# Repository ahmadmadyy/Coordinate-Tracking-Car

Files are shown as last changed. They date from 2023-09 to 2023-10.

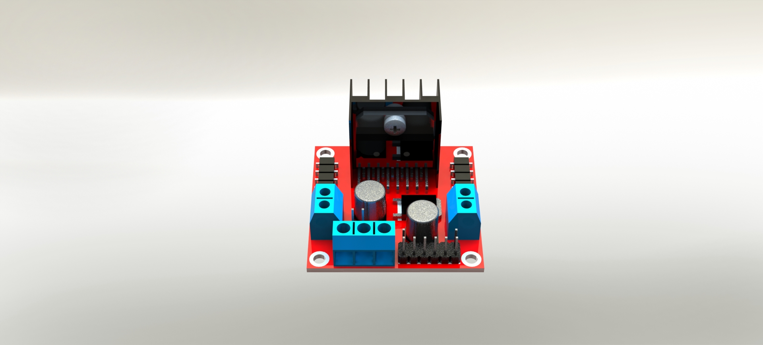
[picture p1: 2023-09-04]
Hardware Design/h_bridg-motor-drive-l298n-1.snapshot.1/Assem final (H_Bridg)/Assem final (H_Bridg)/Untitled63.JPG

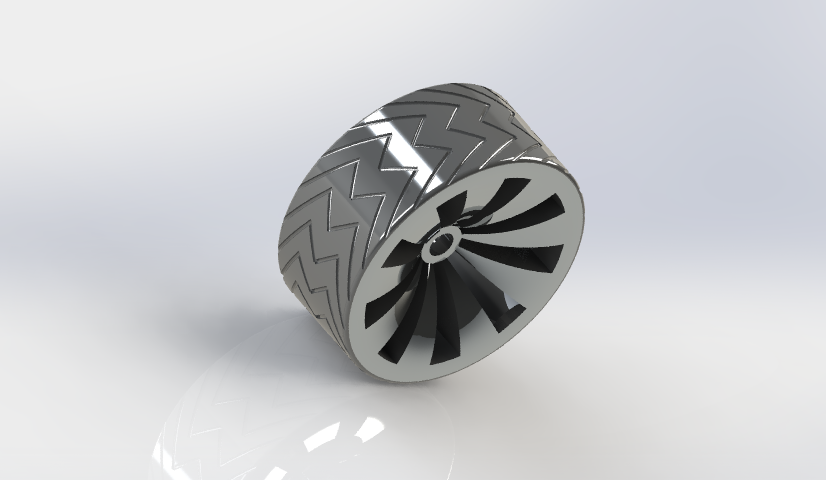
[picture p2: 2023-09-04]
Hardware Design/Capture 2.png

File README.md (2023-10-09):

# Coordinate-Tracking-Car
An AVR-controlled Arduino car that takes as input x and y coordinates from a keypad and uses an encoder sensor with PID Control and PWM to reach its destination.

## Software Design
The software design folder contains the 2 files, an Arduino file that has 2 codes the normal project code and another implemented with FreeRTOS. The second file contains the SIMULINK simulation file and PID controller design.

## Hardware Design 
This folder includes all the Solidworks files and libraries used to design the hardware used.

### Other folders include the images and videos of the project, circuit design and simulation, and the PDF report of the project.

## Youtube Video: 
Video (https://www.youtube.com/watch?v=sBs9JzHG70Q)

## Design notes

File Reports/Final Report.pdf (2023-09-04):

Project Final Report | Mechatronics Engineering MCTR601
Spring 2021

1

# German University in Cairo

## Mechatronics Engineering (MCTR601)

## Coordinate Tracking Car Team 7

Name | ID | Lab Number
Ahmed Khaled Mady | 46-798 | 55
Amro Hassan Abdellatif | 46-3027 | 53
Mostafa Ahmed Kashaf | 46-5456 | 53

Project Final Report | Mechatronics Engineering MCTR601
Spring 2021

2

### Table of Contents

Project Final Report | Mechatronics Engineering MCTR601
Spring 2021

3

## 1. Project Description

The micro-controlled car will be awaiting an input in the form of x-y coordinates through a keypad(3x4). The objective of the car is to reach the desired location. For the car to reach the location, an encoder that measures the number of revolutions required by the motor to reach its destination is used. The output of the encoder will be received by the microcontroller as x-y coordinates to maintain closed-loop feedback control. These x-y coordinates will be calculated using a certain algorithm to be able to know the required speed (v) and rotational torque (θ) of the car. Then the speed and rotational torque will be translated into angular velocity for each wheel (ω_L,ω_R) to accurately reach the destination. When the car reaches its destination, the car will stop.
The car uses a DC gear motor as an actuator and an Infrared motor speed sensor that will be fed back to Arduino’s ATmega328p MCU to maintain a closed loop.
The car will move forward using 2 wheels that are controlled by the motor driver that is controlled by the Arduino development board PWM modes. During turns, left or right, the steering technique is made by increasing the speed of a wheel while keeping the other constant. The turn is made by the single caster wheel.
The car changes its’s angle by measuring the arctan of the y coordinate/ x coordinate and multiplying it with the pulses needed by the motor to rotate. The car is assumed to always given positive x and y coordinates (1ST Quadrant) so the right wheel is always given no PWM signal unlike the left wheel which will cause the rotation.
The x-y coordinates are then used to calculate the needed moving distance, or hypotenuse.

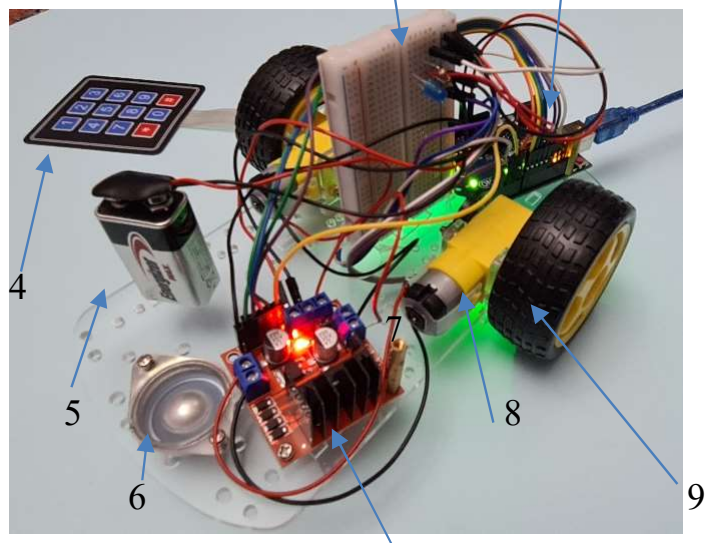
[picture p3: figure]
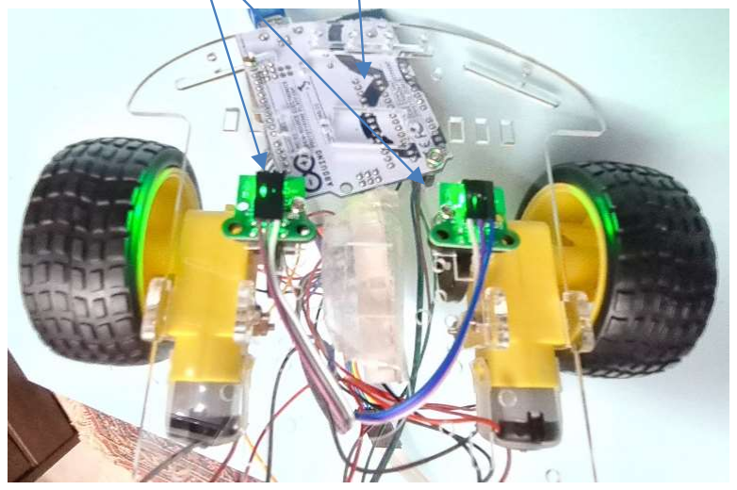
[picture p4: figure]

Project Final Report | Mechatronics Engineering MCTR601
Spring 2021

4

Part number | Name
1 Breadboard
2 Arduino UNO
3 LM393 IR Speed Sensor
4 Keypad
5 9V Battery
6 Caster Wheel
7 L298N Motor Driver
8 DC Gear Motor
9 Wheels

2
1
3 2

7

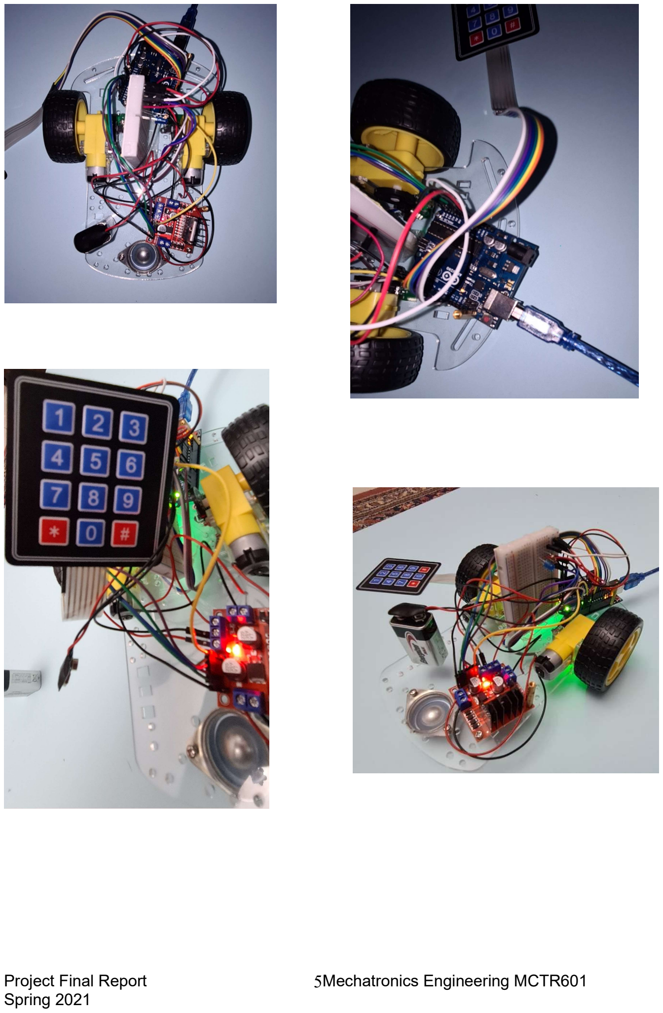
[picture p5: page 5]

Project Final Report | Mechatronics Engineering MCTR601
Spring 2021

5

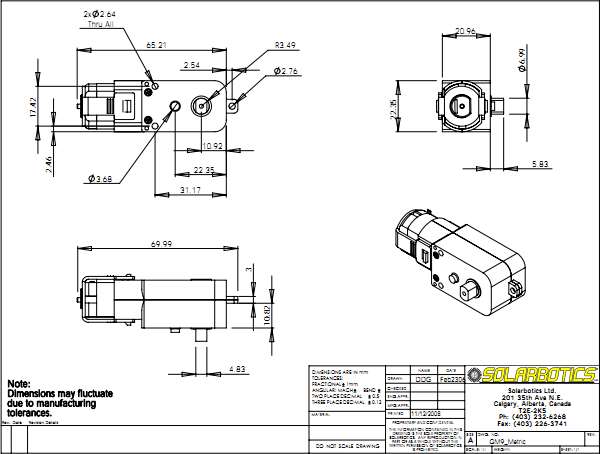
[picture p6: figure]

Project Final Report | Mechatronics Engineering MCTR601
Spring 2021

6

## 2. Methodology

## 2.1 Mechanical design

DC Gear Motor:
Specifications:
Description: 90-degree
Gear ratio: 143:1

### 3 V Operation:

No-load RPM: ~ 40
No-load current: ~ 50 mA
Stall current: ~ 400 mA
Stall torque: ~ 44 oz-in

### 6 V Operation:

No-load RPM: ~ 78
No-load current: ~ 52 mA
Stall current: ~ 700 mA
Stall torque: ~ 76 oz-in
Weight: 33 g

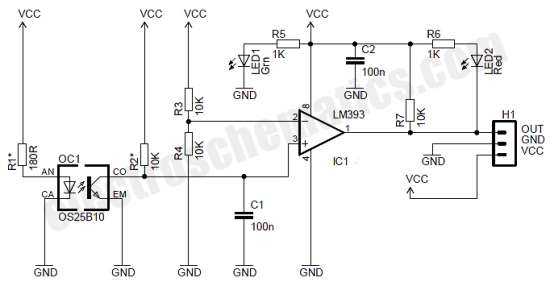
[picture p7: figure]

Project Final Report | Mechatronics Engineering MCTR601
Spring 2021

7

LM393 IR Speed Sensor

Note that one side of the optical sensor holds s a light emitting diode, and a photo transistor on the other side. If the visual path is not blocked, phototransistor would conduct, but when something blocked the light falling on the photo transistor it wouldn’t conduct. So, an encoder disc (with a proper encoder resolution) can be placed in the slot of the optical sensor to count rotation rate of a connected wheel/motor. The encoder disc (also known as index wheel) in the above image have multiple slots/holes.

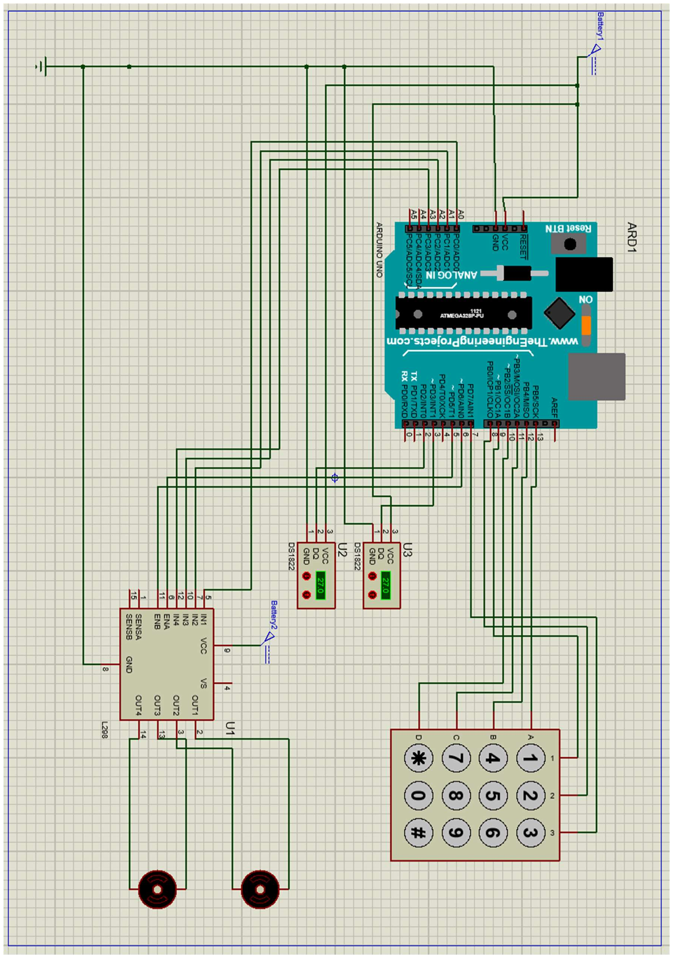
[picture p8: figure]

Project Final Report | Mechatronics Engineering MCTR601
Spring 2021

8

## 2.2 Electrical design

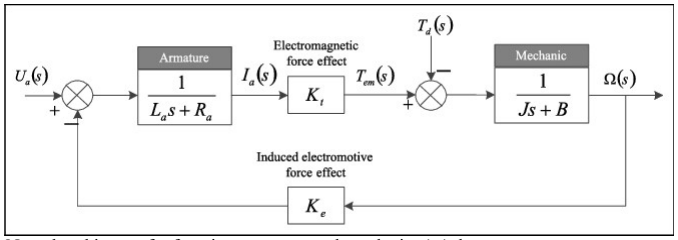
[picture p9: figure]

Project Final Report | Mechatronics Engineering MCTR601
Spring 2021

9

## 2.3 Control

### 1.3.1. Modeling

a. DC MOTOR:
From the datasheet of the DC geared motor, the following parameters were obtained:
(J) Moment of inertia of the rotor 0.1 kg.m
(B) Motor viscous friction constant 0.3550510258 N.m.s
(Ke) Electromotive force constant | 0.25 V/rad/sec
(Kt) Motor torque constant | 0.01 N.m/Amp
(R) Electric resistance | 0.4222474487 Ohm
(L) Electric inductance | 0.05 H
Transfer Function:

### 1.3.2. Analysis

Note that this transfer function outputs angular velocity (ω), but our purposes are revolutions, so an integrator was added at the output.
On MATLAB, the transfer function was generated
L_a = 0.05;
J_m = 0.1;
B = 0.3550510258;
R_a = 0.4224744871;
K_e = 0.25;
K_t = 0.01;
Armature= tf([1],[L_a R_a]); A = series(K_t,Armature);
Mechanical = tf([1],[J_m B]); M = series(A,Mechanical);
W = feedback(M,K_e);
G = series(W,tf([1],[1 0])

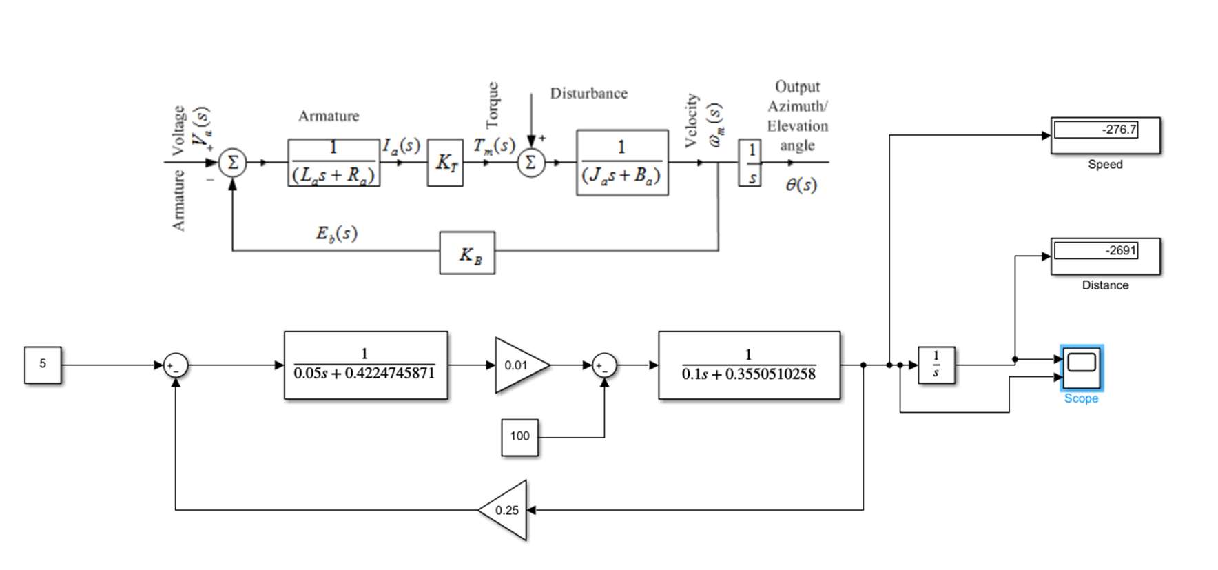
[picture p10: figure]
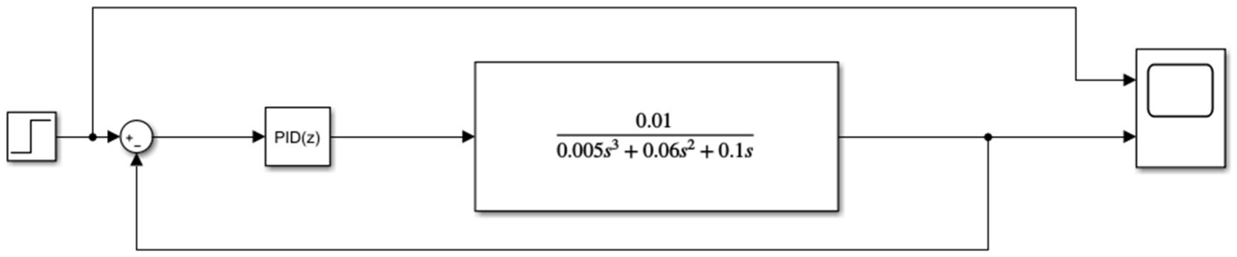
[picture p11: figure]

Project Final Report | Mechatronics Engineering MCTR601
Spring 2021 | 10

SIMULINK DIAGRAM:

Plant:
G =

0.01
-------------------------------0.005 s^3 + 0.06 s^2 + 0.1525 s

Continuous-time transfer function.

### 1.3.3. Controller Design

To design our controller, we modeled our system on SIMULINK:

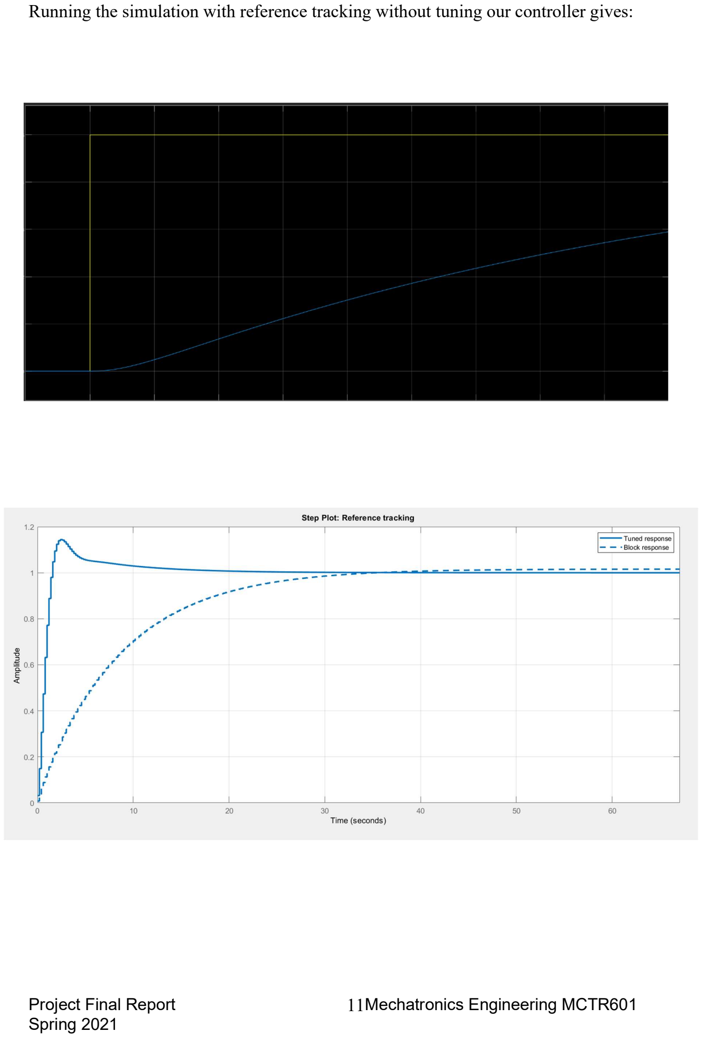
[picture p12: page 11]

Project Final Report | Mechatronics Engineering MCTR601
Spring 2021 | 11

Running the simulation with reference tracking without tuning our controller gives:

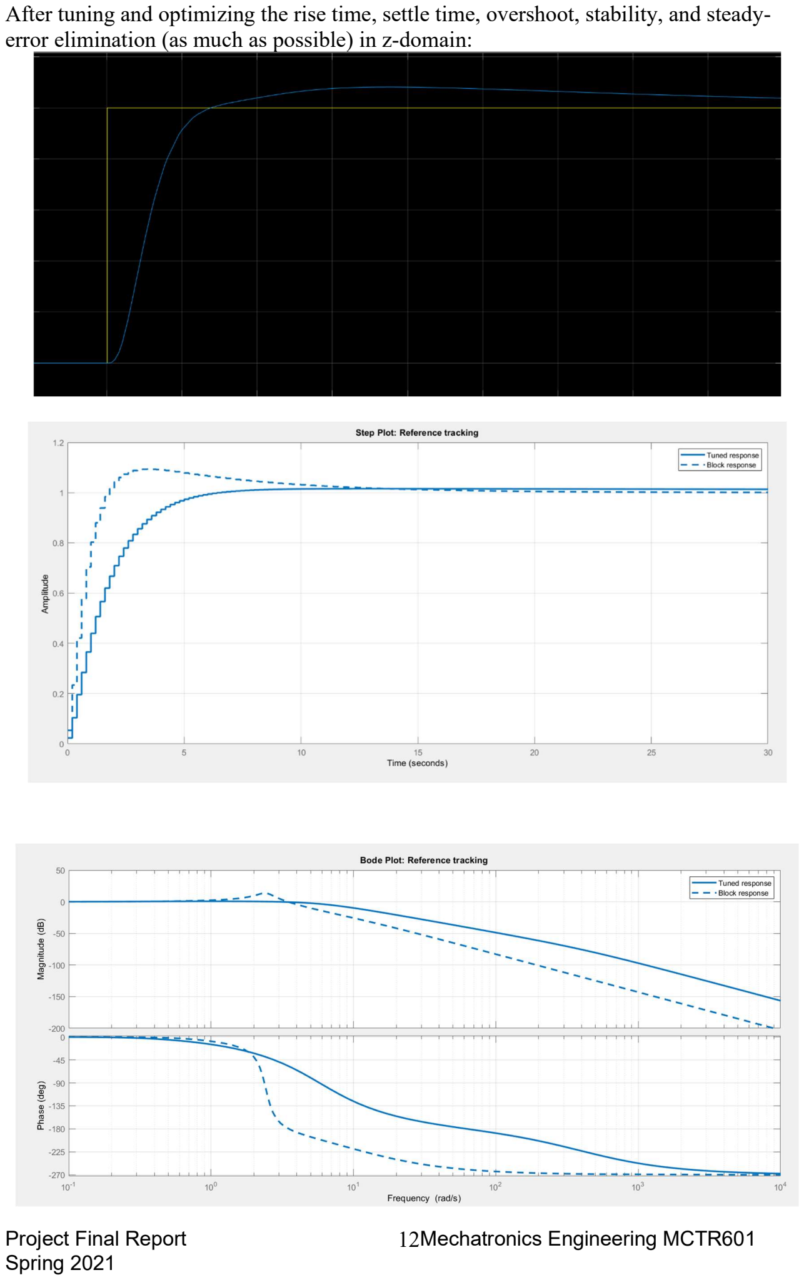
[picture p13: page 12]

Project Final Report | Mechatronics Engineering MCTR601
Spring 2021 | 12

After tuning and optimizing the rise time, settle time, overshoot, stability, and steady-error elimination (as much as possible) in z-domain:

Project Final Report | Mechatronics Engineering MCTR601
Spring 2021

13

Control Law with a PID Compensator: K + K

+ K

with
Kp=13.83;
Kd=7.3;
Ki=2;

13.83 + 2

1
z − 1 + 7.3

z − 1
z

Project Final Report | Mechatronics Engineering MCTR601
Spring 2021

14

## 2.4 Programming

#include <math.h>

#include <Keypad.h>

//Keypad
const byte ROWS = 4;
const byte COLS = 3;
char hexaKeys[ROWS][COLS] = {
{'1', '2', '3'},
{'4', '5', '6'},
{'7', '8', '9'},
{'*', '0', '#'}
};
byte rowPins[ROWS] = {13, 12, 11, 10};
byte colPins[COLS] = {9, 8, 7};
Keypad customKeypad = Keypad(makeKeymap(hexaKeys), rowPins, colPins, ROWS, COLS);
String inputString;
long inputInt;
//Flags
char inputTaken = 1;
char rotated = 1;
char xDone = 1;
char moved1 = 1;
char moved2 = 1;
//Encoder reading vatriables unsigned int rpm1 = 0;
unsigned int rpm2 = 0;
int target;
float velocity1=0; | //Velocidad en [Km/h]
float velocity2=0;
volatile int pulses1 = 0;
volatile int pulses2 = 0;
static volatile unsigned long debounce1 = 0; static volatile unsigned long debounce2 = 0; //position variables
int x;
int y;
signed int theta;
int ref=0;
int dist=0;
//PID gains
double Kp=13.83;
double Kd=7.3;
double Ki=2;
//1st Motor

Project Final Report | Mechatronics Engineering MCTR601
Spring 2021

15

signed int e1=0;
float PID1_Kp=0;
float PID1_Kd=0;
float PID1_Ki=0;
int PrevE1=0;
int PWM1=0;
int PWMmap1=0;
float PID1=0;
//2nd Motor
signed int e2=0;
float PID2_Kp=0;
float PID2_Kd=0;
float PID2_Ki=0;
int PrevE2=0;
int PWM2=0;
int PWMmap2=0;
float PID2=0;
unsigned long prevTime = 0; unsigned long timeold1 = 0; unsigned long timeold2 = 0; unsigned long time1 = 0;
unsigned int pulsesperturn = 20;
const int wheel_diameter = 64;
void setup() {
Serial.begin(9600); // Configuración del puerto serie pinMode(14,OUTPUT);
pinMode(15,OUTPUT);
pinMode(5,OUTPUT);
pinMode(6,OUTPUT);
pinMode(16,OUTPUT);
pinMode(17,OUTPUT);
pinMode(18,OUTPUT);
digitalWrite(14,LOW);
digitalWrite(15,HIGH);
digitalWrite(16,LOW);
digitalWrite(17,HIGH);
attachInterrupt(0, counter1, RISING); attachInterrupt(1, counter2, RISING); x=400;
y=400;

}
void counter1(){
if( digitalRead (2) && (micros()-debounce1 > 500) && digitalRead (2) ) {

Project Final Report | Mechatronics Engineering MCTR601
Spring 2021

16

debounce1 = micros();
pulses1++;
}
else ;
}
void counter2(){
if( digitalRead (3) && (micros()-debounce2 > 500) && digitalRead (3) ) {
debounce2 = micros();
pulses2++;
}
else ;
}
void loop() {
if(inputTaken)
{
char customKey = customKeypad.getKey();
if(xDone){
if (customKey =='0' ||customKey =='1'||customKey =='2'||customKey =='3'||customKey =='4'
|| customKey =='5'||customKey =='6'||customKey =='7'||customKey =='8'||customKey =='9') { // only act on numeric keys
inputString += customKey;
//Serial.println(inputString);// append new character to input string
} else if (customKey == '*') {
if (inputString.length() > 0) {
inputInt = inputString.toInt(); // YOU GOT AN INTEGER NUMBER //Serial.println(inputString);
x = inputInt;
Serial.print("x = ");
Serial.println(x);
inputString = ""; | // clear input
xDone = 0;
delay(50);

}
}
}
else if(!xDone) {
if (customKey =='0' ||customKey =='1'||customKey =='2'||customKey =='3'||customKey =='4'
|| customKey =='5'||customKey =='6'||customKey =='7'||customKey =='8'||customKey =='9') { // only act on numeric keys
inputString += customKey;
//Serial.println(inputString);// append new character to input string
} else if (customKey == '*') {

Project Final Report | Mechatronics Engineering MCTR601
Spring 2021

17

if (inputString.length() > 0) {
inputInt = inputString.toInt(); // YOU GOT AN INTEGER NUMBER //Serial.println(inputString);
y = inputInt;
Serial.print("y = ");
Serial.println(y);
inputString = ""; | // clear input
xDone = 1;
delay(50);

}
if(y == 0){
theta = -1;
}
else{
theta = x/y;
}
inputTaken = 0;
delay(5000);
}

}

}
//encoder readings
time1 = millis();
if (millis() - timeold1 >= 1000){ // Se actualiza cada segundo
noInterrupts(); //Don't process interrupts during calculations // Desconectamos la interrupción para que no actué en esta parte del programa.
rpm1 = (60UL * 1000 / pulsesperturn )/ (millis() - timeold1)* pulses1; // Calculamos las revoluciones por minuto
velocity1 = rpm1 * 3.1416 * wheel_diameter * 60 / 1000000; // Cálculo de la velocidad en [Km/h]
timeold1 = millis(); // Almacenamos el tiempo actual.
interrupts();
}

if (millis() - timeold2 >= 1000){ // Se actualiza cada segundo
noInterrupts(); //Don't process interrupts during calculations // Desconectamos la interrupción para que no actué en esta parte del programa.
rpm2 = (60UL * 1000 / pulsesperturn )/ (millis() - timeold2)* pulses2; // Calculamos las revoluciones por minuto
velocity2 = rpm2 * 3.1416 * wheel_diameter * 60 / 1000000; // Cálculo de la velocidad en [Km/h]
timeold2 = millis(); // Almacenamos el tiempo actual.
interrupts();

Project Final Report | Mechatronics Engineering MCTR601
Spring 2021

18

}
// Car rotation
if(rotated & !inputTaken){ Serial.println(theta);
if(theta<0){
target = (175/(4*3.1416))*(1.5708); }
else{
target = (175/(4*3.1416))*atan(theta); }
while(pulses1 < target){
//Serial.print(2);
digitalWrite(14,LOW);
digitalWrite(15,HIGH);
analogWrite(5,160);
}
analogWrite(5,0);
pulses1 = 0;
pulses2 = 0;
rotated = 0;
delay(2500);
}

// Moving in straight line if(!rotated & !inputTaken){
dist = sqrt((pow(x,2) + pow(y,2))); ref = (dist/(6.2832*32))*20;

//PID1 readings
e1 = ref - pulses1;
PID1_Kp = Kp*e1;
PID1_Ki = PID1_Ki +(Ki*e1);
PID1_Kd = Kd*(e1-PrevE1)/(time1-prevTime); PID1 = PID1_Kp + PID1_Ki + PID1_Kd;

if(PID1 < 0){
PWM1 = -1*PID1;
digitalWrite(14,HIGH);
digitalWrite(15,LOW);
digitalWrite(16,LOW);
digitalWrite(17,HIGH);
}
else{
PWM1 = PID1;
digitalWrite(14,LOW);
digitalWrite(15,HIGH);

Project Final Report | Mechatronics Engineering MCTR601
Spring 2021

19

digitalWrite(16,LOW);
digitalWrite(17,HIGH);
Serial.println(PID1);
}

//PID2 readings
e2 = ref - pulses2;
PID2_Kp = Kp*e2;
PID2_Ki = PID2_Ki +(Ki*e2);
PID2_Kd = Kd*(e2-PrevE2)/(time1-prevTime); PID2 = PID2_Kp + PID2_Ki + PID2_Kd; if(PID2 < 0){
PWM2 = -1*PID2;
digitalWrite(14,LOW);
digitalWrite(15,HIGH);
digitalWrite(16,HIGH);
digitalWrite(17,LOW);
}
else{
PWM2 = PID2;
digitalWrite(14,LOW);
digitalWrite(15,HIGH);
digitalWrite(16,LOW);
digitalWrite(17,HIGH);
}
//Motor1
if(!(-1 < e1 <1)){
analogWrite(5,PWM1);
}
else{
analogWrite(5,0);
moved1 = 0;
}
//Motor2
if(!(-1 < e2 <1)){
analogWrite(6,PWM2);
}
else{
analogWrite(6,0);
moved2 = 0;

}
prevTime = time1;
PrevE1 = e1;
PrevE2 = e2;
}

Project Final Report | Mechatronics Engineering MCTR601
Spring 2021

20

if((!moved1) & (!moved2) ) {
delay(1000);
digitalWrite(18,HIGH);
inputTaken = 1;
rotated = 1;
xDone = 1;
moved1 = 1;
moved2 = 1;
pulses1 = 0;
pulses2 = 0;
}

}

Project Final Report | Mechatronics Engineering MCTR601
Spring 2021

21

## 3. Design Evaluation

As in any design there are always flaw factors which were not taken into consideration and had a somewhat negative and unpredictable effect on the actual experimental performance. To start with the tires of the wheels were made of a smooth material and even though it did have some marks on it to create for the necessary friction, it was found that some floors didn’t enough traction, causing the wheel to slip and the encoder to count rotations which did to contribute to the distance moved and hence missing the intended end position and sometimes ended up undershooting. So, the surface played a factor which we were

unable to take into account.
Another problem was that even though both gear motors were identical,

### there was a difference in performance between each motor due to small

differences in internal friction of the motors and inductance.

### This problem did contribute some unwanted results but was overcome by having separate encoder readings for each wheel to compensate for different rotational speeds to ensure each wheel has rotated the

intended number of turns.

### A factor which added to the difference in performance in each motor

was the fact that the weight of the components used (Arduino,

### breadboard and the l298N motor driver) were not evenly distributed over the whole car which was a flaw in our design. Proper positioning of these components would have evened the weight on each wheel hence

reducing the noticeable difference in each wheel’s rotational speed.

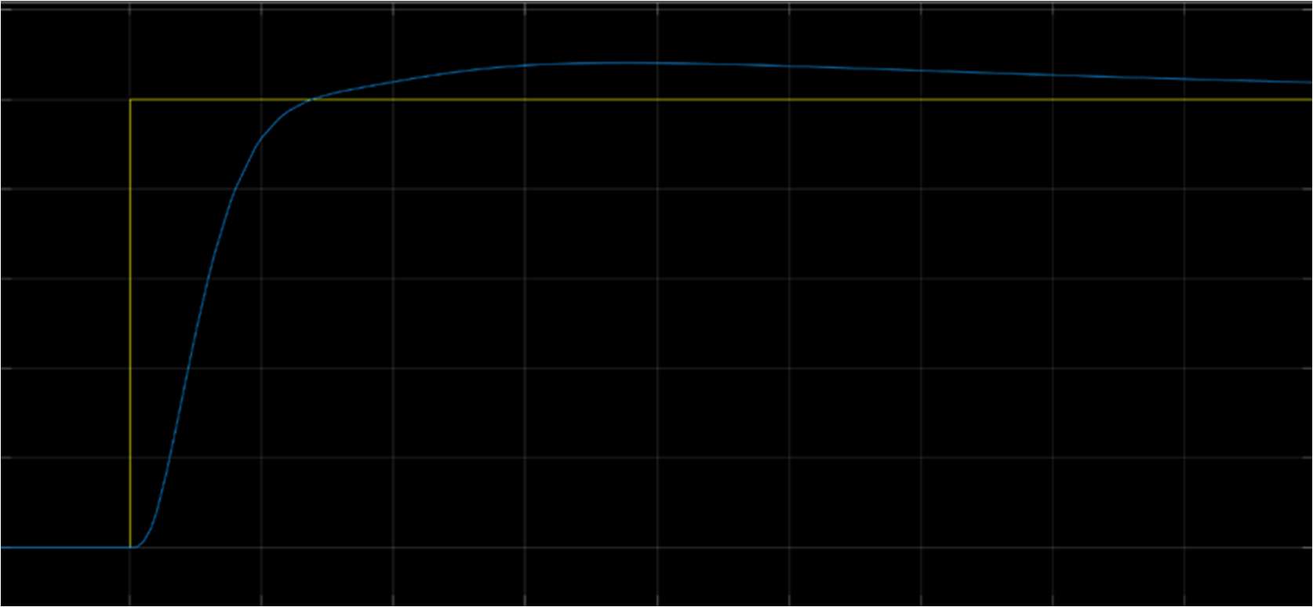
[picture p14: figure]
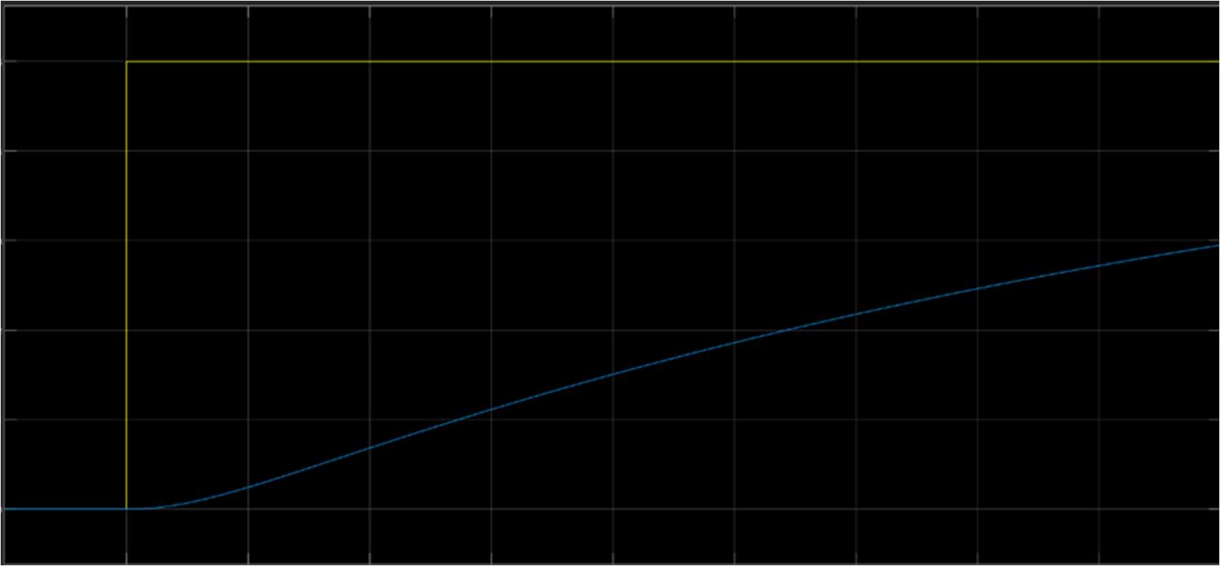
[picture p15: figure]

Project Final Report | Mechatronics Engineering MCTR601
Spring 2021 | 22

## WITH PID:

## NO PID:

Project Final Report | Mechatronics Engineering MCTR601
Spring 2021

23

## 4. Appendix

Keypad Library Arduino:
char getKey(): Returns the key that is pressed, if any. This function is non-blocking. Creation:

Constructors:

Keypad(makeKeymap(userKeymap), row[], col[], rows, cols)

const byte rows = 4; //four rows
const byte cols = 3; //three columns
char keys[rows][cols] = {
{'1','2','3'},
{'4','5','6'},
{'7','8','9'},
{'#','0','*'}
};
byte rowPins[rows] = {5, 4, 3, 2}; //connect to the row pinouts of the keypad
byte colPins[cols] = {8, 7, 6}; //connect to the column pinouts of the keypad
Keypad keypad = Keypad( makeKeymap(keys), rowPins, colPins, rows, cols );

Instantiates a Keypad object that uses pins 5, 4, 3, 2 as row pins, and 8, 7, 6 as column pins.
This keypad has 4 rows and 3 columns, resulting in 12 keys.

Project Final Report | Mechatronics Engineering MCTR601
Spring 2021

24

## 5. Sources

### 1. https://www.mathworks.com/matlabcentral/fileexchange/80482-mathematical-

transfer-function-modelling-of-dc-motor

### 2. https://www.electroschematics.com/motor-speed-sensor-module-circuit/ 3. https://nationalmaglab.org/education/magnet-academy/watch-play/interactive/dc-

motor

### 4. https://howtomechatronics.com/tutorials/arduino/rotary-encoder-works-use-

arduino/

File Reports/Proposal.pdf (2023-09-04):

# Coordinate Tracking Car

## Proposal Mechatronics Engineering MCTR 601 Ahmed Khaled Mady (46-798) T55 Amro Hassan Abdellatif (46-3027) T53 Mostafa Ahmed Kashaf (46-5456) T53

5/11/2021

## Dr. Ayman A. El-Badawy

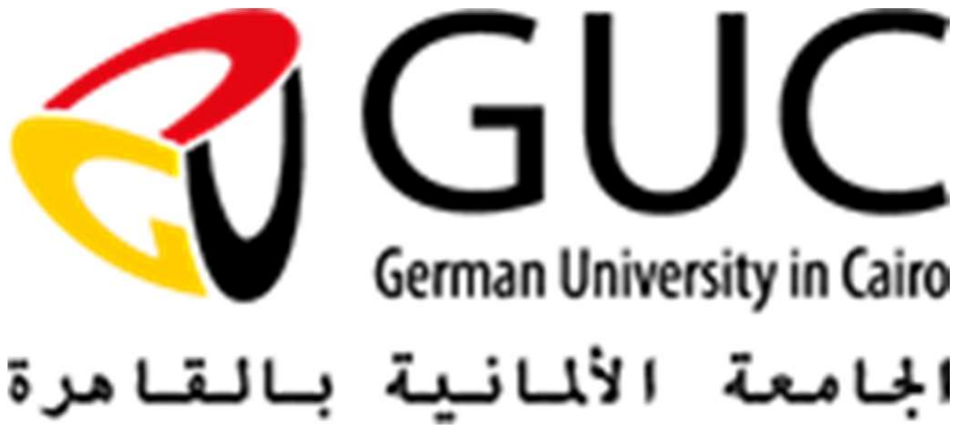
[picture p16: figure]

Device Behavior Description
The micro-controlled car will be awaiting an input in the form of x-y coordinates through a keypad(3x4). The objective of the car is to reach the desired location. For the car to reach the location, we will use an encoder that measures the number of revolutions required by the motor to reach its destination. The output of the encoder will be received by the micro-controller as x-y coordinates to maintain closed-loop feedback control. These x-y coordinates will be calculated using a certain algorithm to be able to know the required speed (v) and rotational torque ( ) of the car. Then using Differential Robot Model in MATLAB (Differential Drive), we will translate the speed and rotational torque into angular velocity for each wheel (

, ) to
accurately reach the destination. When the car reaches its destination, LEDs will turn on.
Device Design
The car will move forward using 2 wheels that are controlled by the motor driver that is controlled by the Arduino development board PWM modes. During turns, left or right, the steering technique is made by increasing the speed of a wheel while keeping the other constant. The turn is made by the single caster wheel.

Main Components

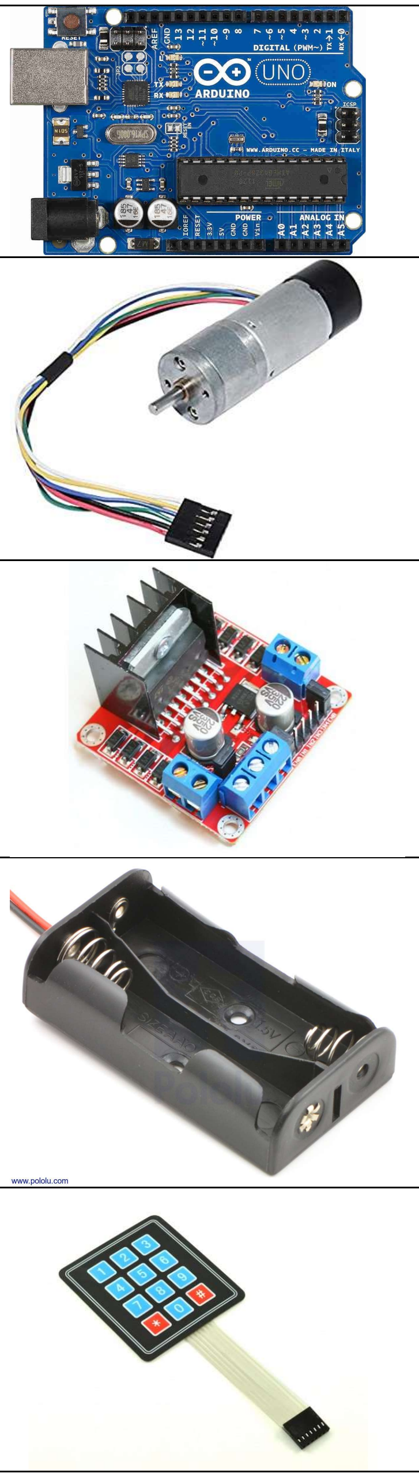
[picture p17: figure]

Arduino Uno Development Board

DC MOTOR with Encoder (8.8 Kg.cm - 133 RPM - 6:12V)

1x L298N Motor Driver (H Bridge)

Batteries and battery holder

Standard Matrix Key Pad 3×4 Flat

Circuit Diagram

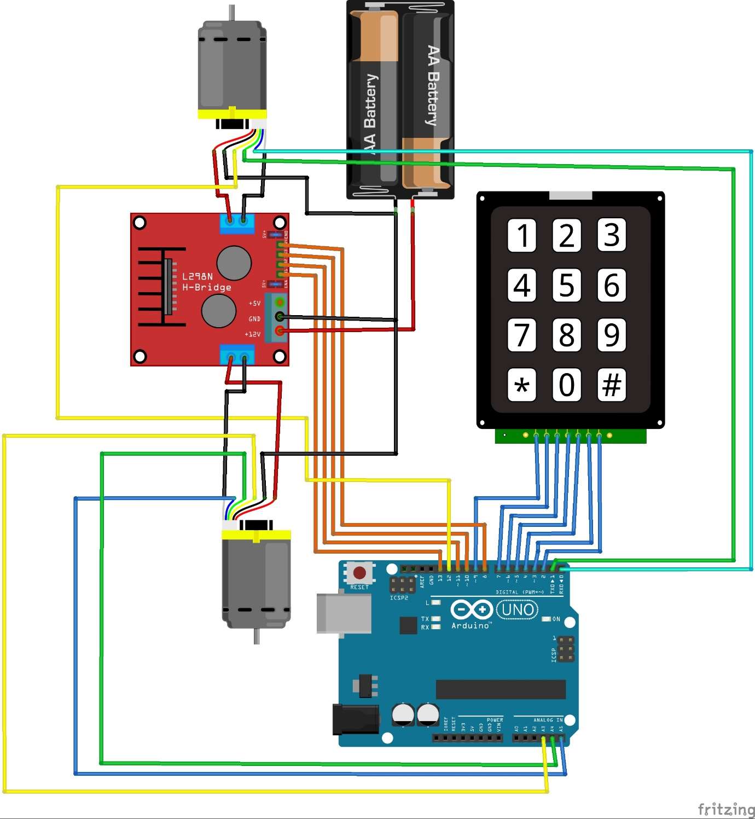
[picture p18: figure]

Proposed Design

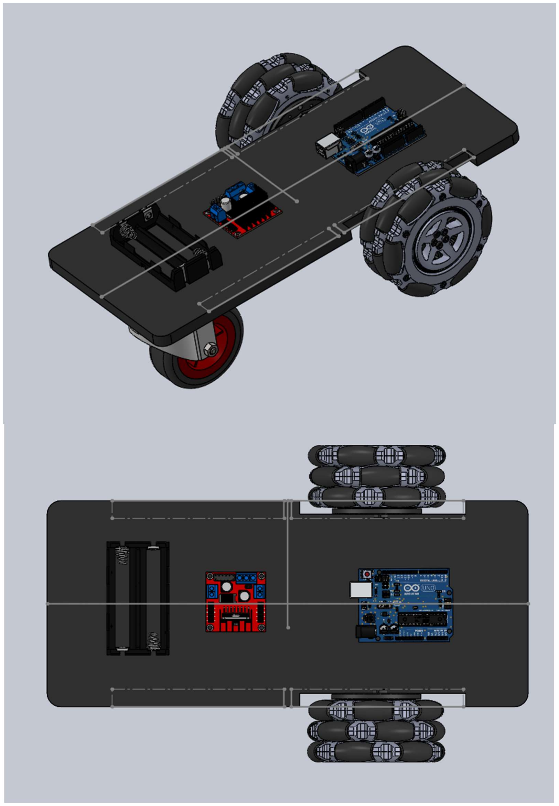
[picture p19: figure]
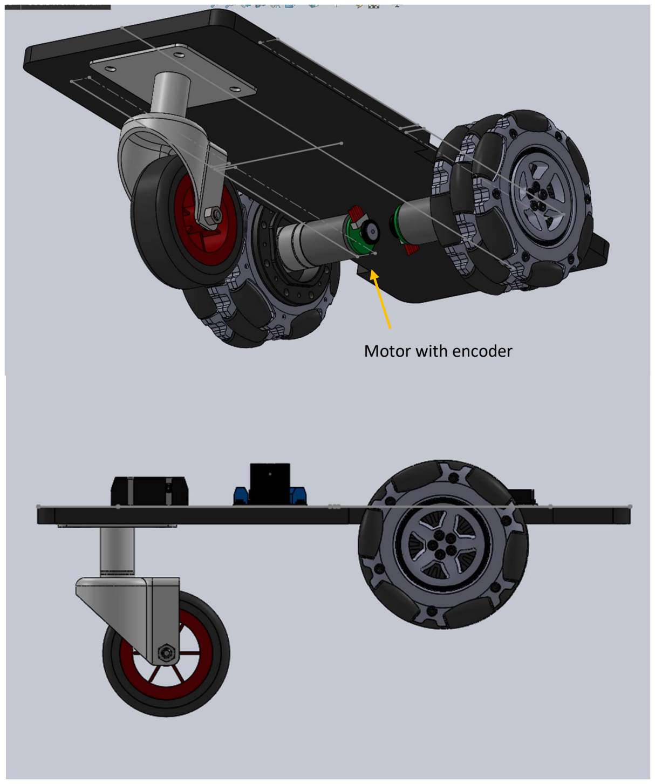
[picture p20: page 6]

Motor with encoder

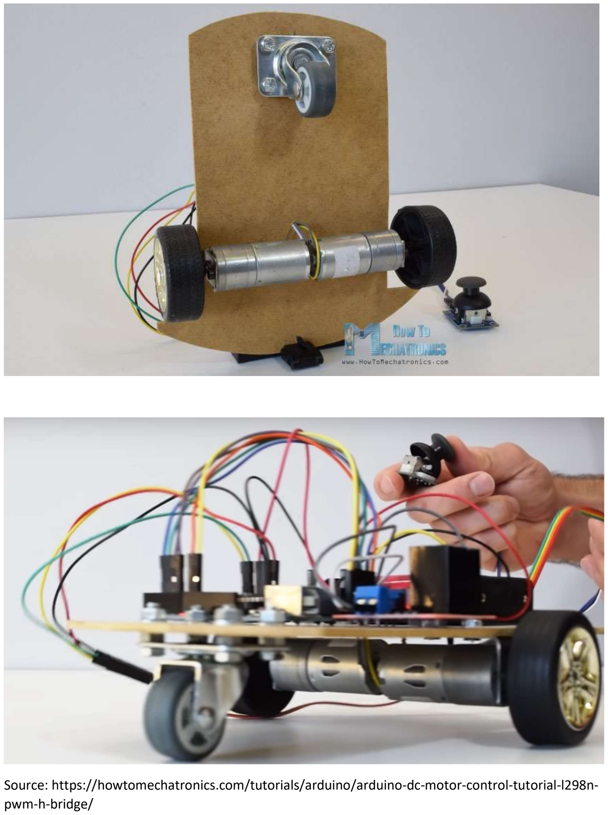
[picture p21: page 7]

Source: https://howtomechatronics.com/tutorials/arduino/arduino-dc-motor-control-tutorial-l298npwm-h-bridge/

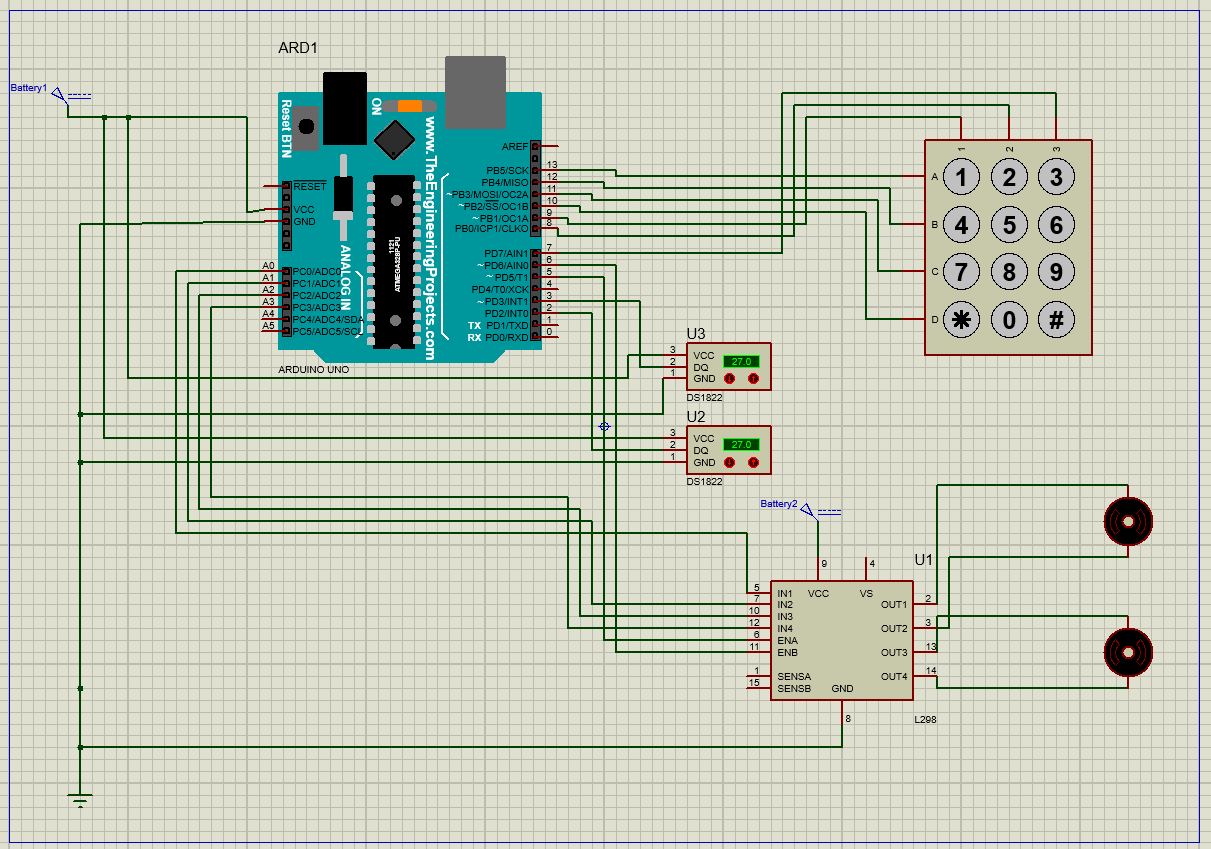
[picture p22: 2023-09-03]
Circuit Diagram/Circuit Schematic.png

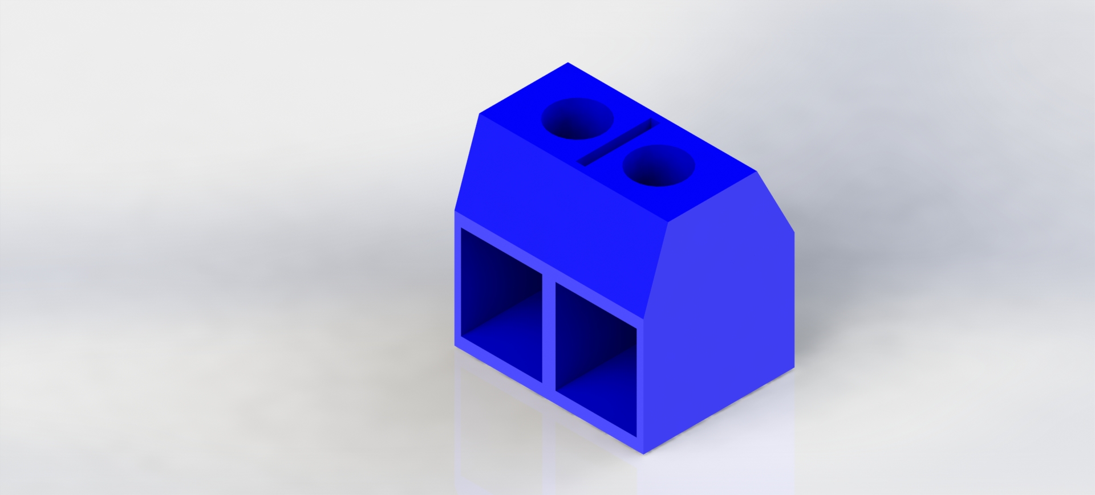
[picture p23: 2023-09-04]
Hardware Design/h_bridg-motor-drive-l298n-1.snapshot.1/Assem final (H_Bridg)/Assem final (H_Bridg)/New folder/Untitled4.JPG

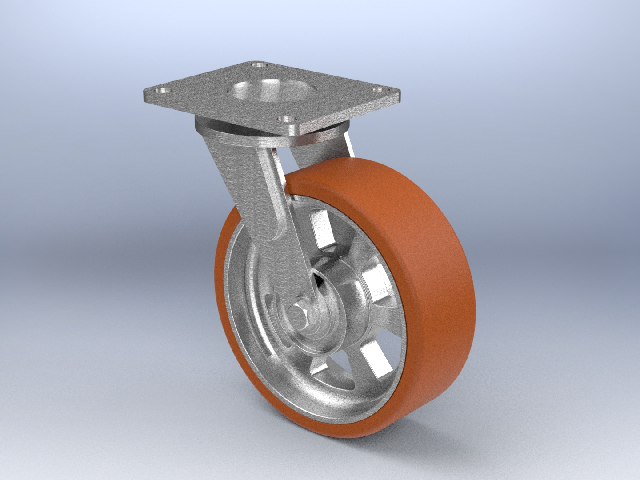
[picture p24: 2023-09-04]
Hardware Design/Поворотные колесо d200мм/render_4.jpg

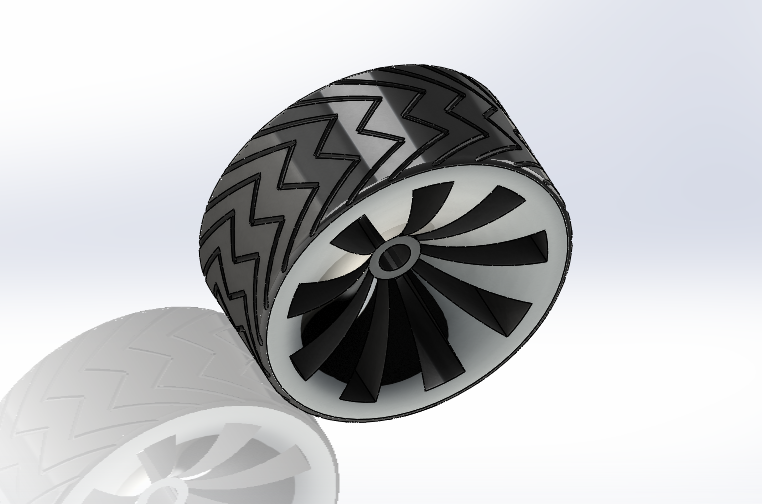
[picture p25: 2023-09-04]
Hardware Design/Capture .png

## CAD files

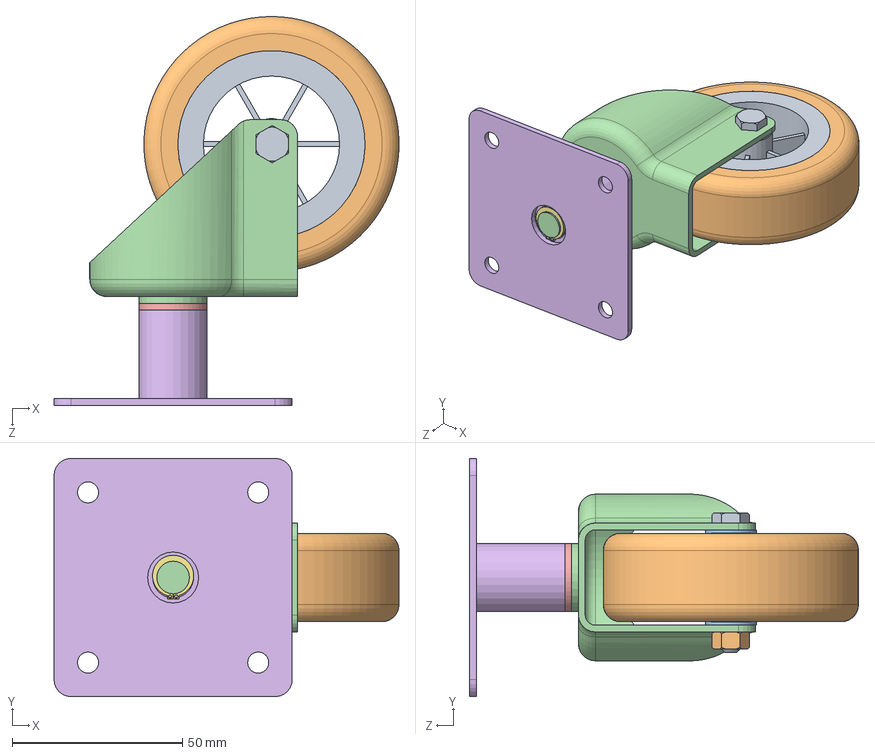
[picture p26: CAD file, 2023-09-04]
Hardware Design/wheel/Assem2.SLDASM
101.4 x 70.0 x 114.3 mm
wheel
tire
Washer x 2
wheel carrier
bearing
Support plate
Ring
pipe
screw M6
screw nut m6

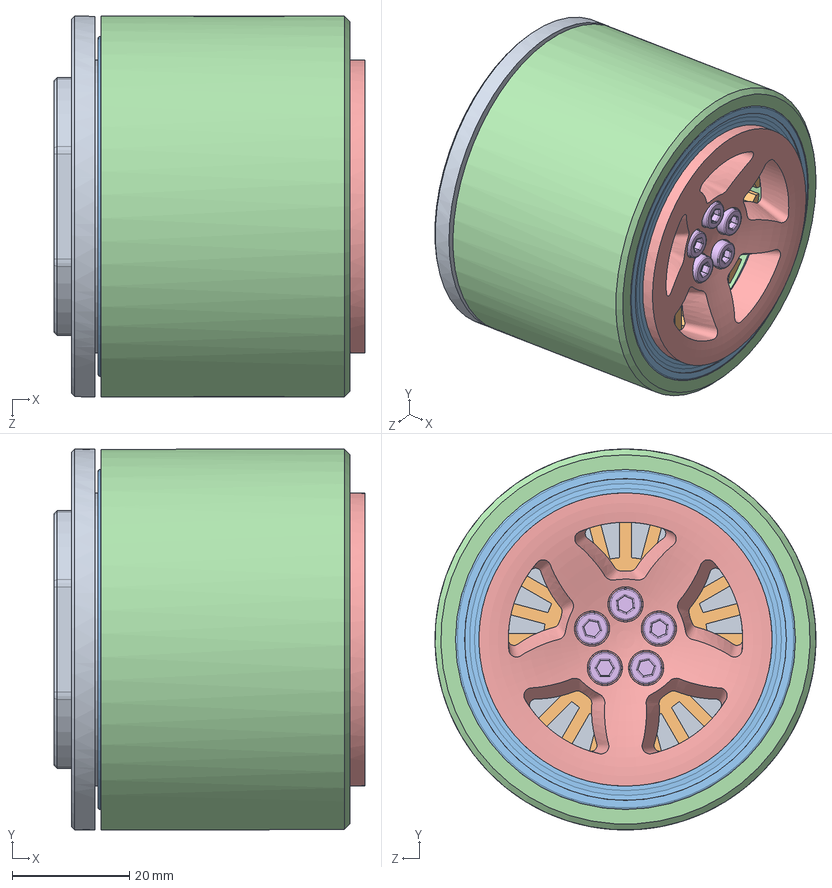
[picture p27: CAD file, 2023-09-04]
Hardware Design/Direct Drive Motor.SLDASM
53.0 x 65.0 x 65.0 mm
DDM Bace
DDm Stator laminet
W 61809-2RS1 x 2
DDM Rotor
DDM Cap
DDM M3-15mmscrew x 5

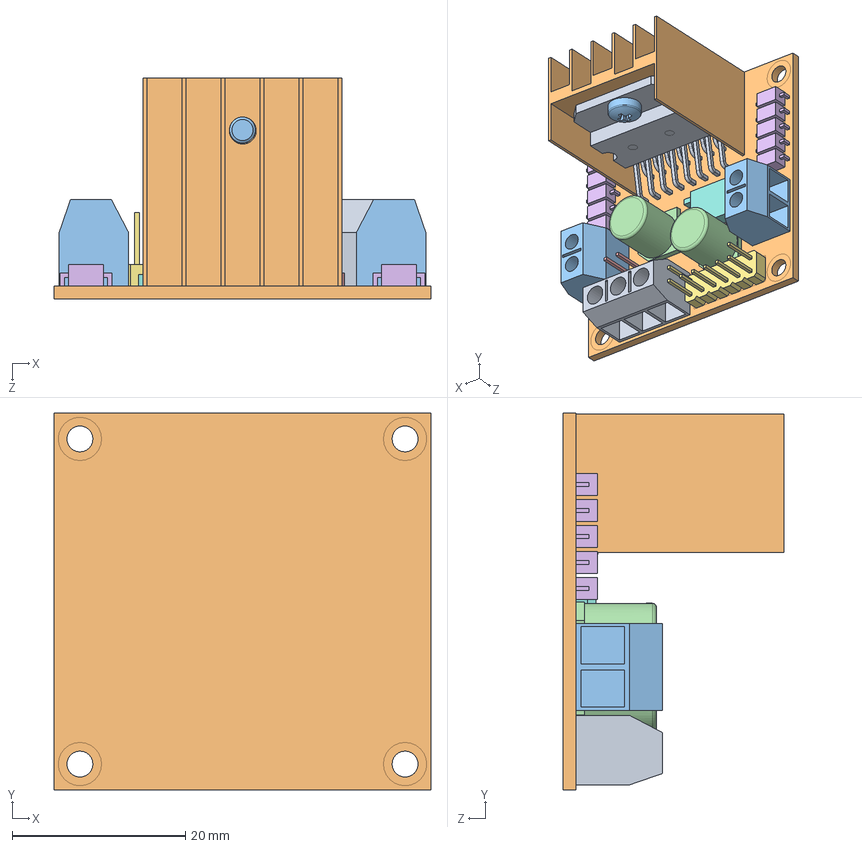
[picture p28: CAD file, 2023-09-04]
Hardware Design/h_bridg-motor-drive-l298n-1.snapshot.1/Assem final (H_Bridg)/Assem1 (H_Bridg motor drive L298N).SLDASM
43.5 x 43.5 x 25.5 mm
Screw terminal 3 way
HEIT SINK
Screw terminal 2 way x 2
Capacitor x 2
Dual pin header
Diode x 10
Pin header
Regulator
L298N
BCP
pan head cross recess screw_din

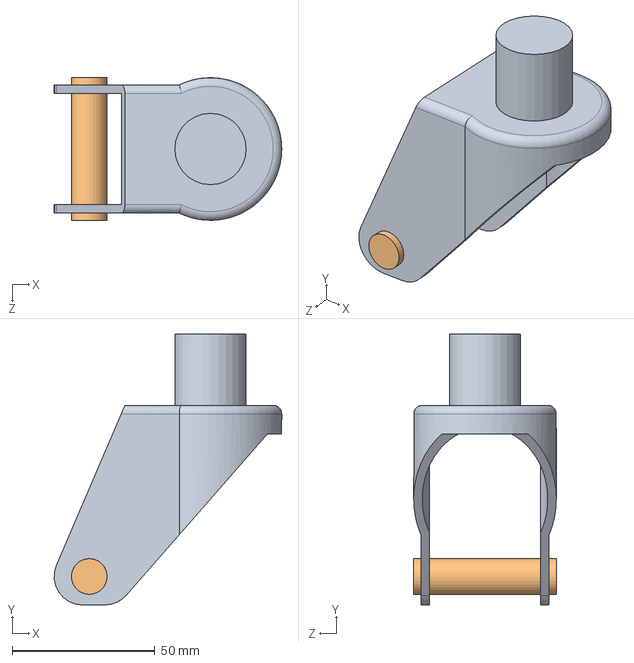
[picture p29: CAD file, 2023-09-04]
Hardware Design/Guide wheel.SLDASM
79.8 x 95.0 x 50.0 mm
Bracket D
Cross shaft D

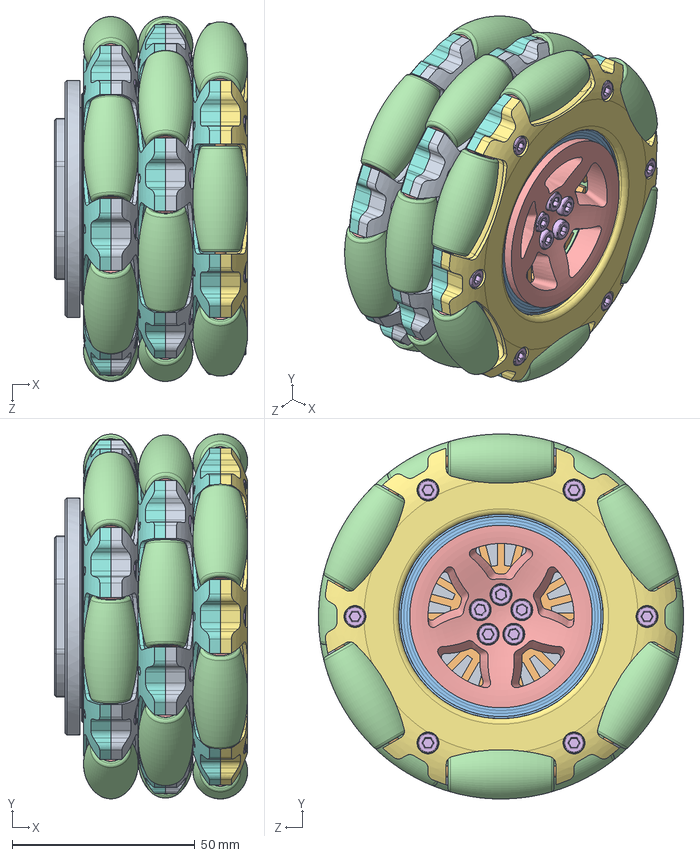
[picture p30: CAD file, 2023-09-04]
Hardware Design/Driect Drive Omni Wheel.SLDASM
53.0 x 100.0 x 100.0 mm
DDM Bace
DDm Stator laminet
W 61809-2RS1 x 2
DDM Rotor
DDM Cap
DDM M3-15mmscrew x 5
DDOW Part 2
DDOW Part 5 x 3
DDOW Part 3 x 2
DDOW Roller Shaft x 33
DDOW Suport Shaft x 18
DDOW Roller x 18
W 638_3 R-2RS1 x 36
DDOW M3-15mmscrew x 18

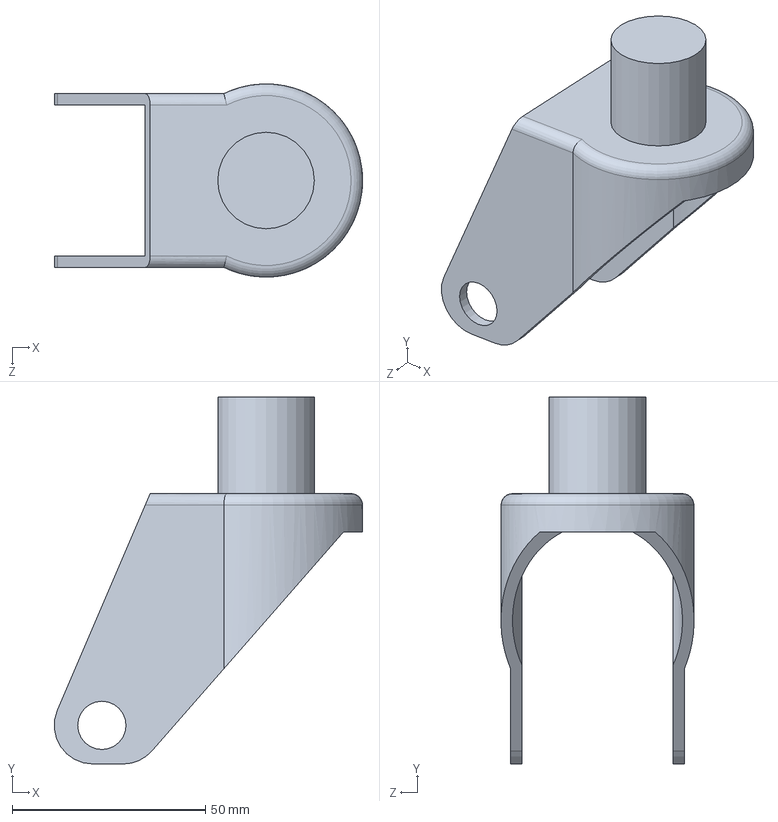
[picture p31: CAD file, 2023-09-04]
Hardware Design/Bracket D.SLDPRT
79.8 x 95.0 x 50.0 mm

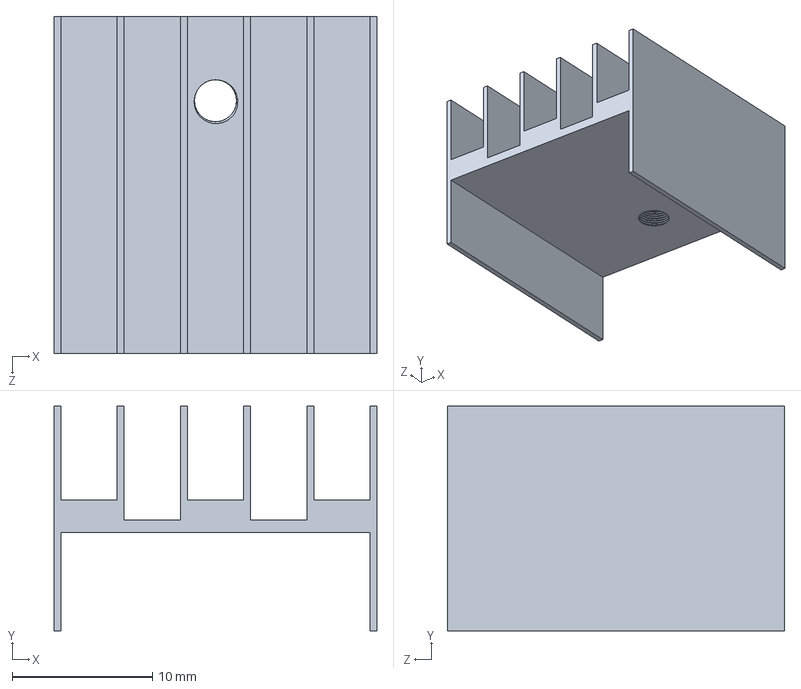
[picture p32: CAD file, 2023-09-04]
Hardware Design/h_bridg-motor-drive-l298n-1.snapshot.1/Assem final (H_Bridg)/HEIT SINK.SLDPRT
23.0 x 16.0 x 24.0 mm

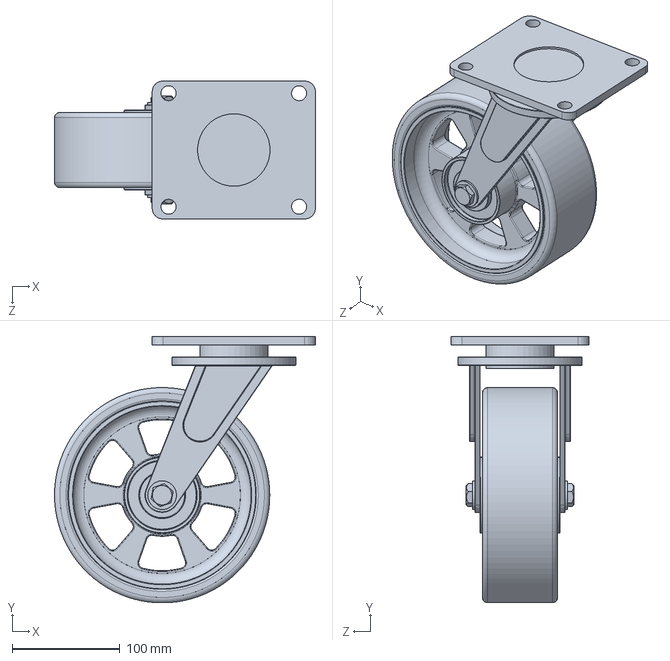
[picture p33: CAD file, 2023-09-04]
Hardware Design/Поворотные колесо d200мм/Поворотные колеса d200мм.SLDPRT
242.5 x 247.5 x 128.2 mm

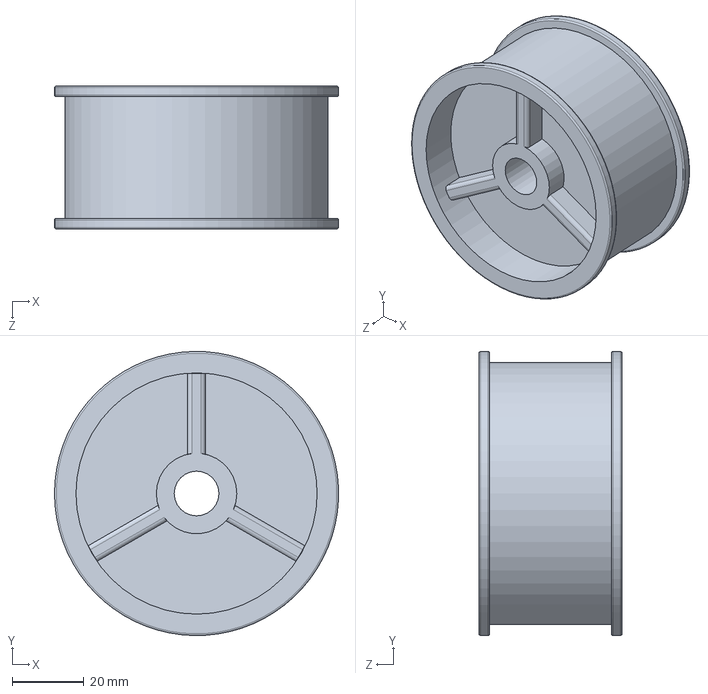
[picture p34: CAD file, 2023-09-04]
Hardware Design/Base rim.SLDPRT
79.4 x 79.4 x 40.0 mm

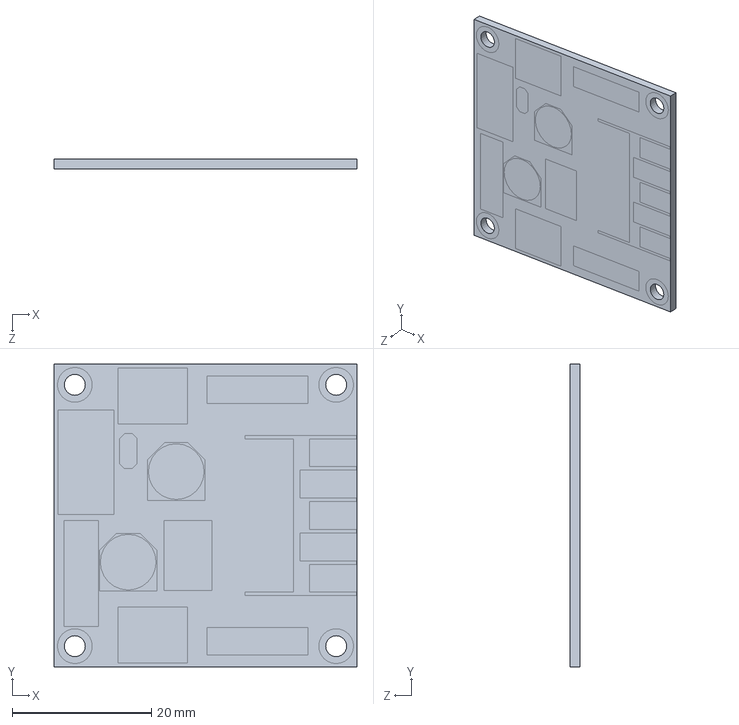
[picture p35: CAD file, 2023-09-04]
Hardware Design/h_bridg-motor-drive-l298n-1.snapshot.1/Assem final (H_Bridg)/BCP.SLDPRT
43.5 x 43.5 x 1.50 mm

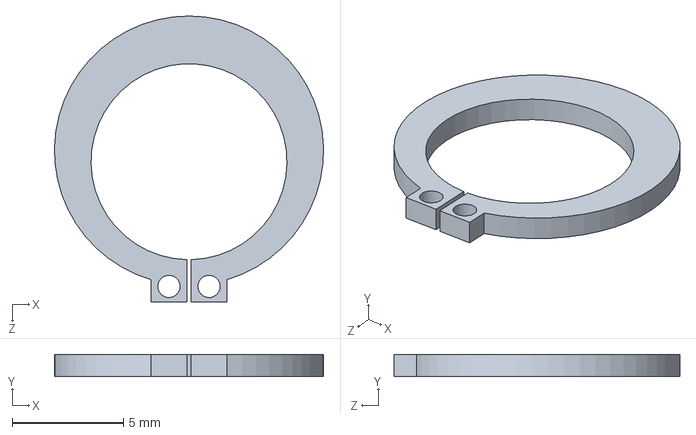
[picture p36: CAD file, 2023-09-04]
Hardware Design/wheel/Ring.SLDPRT
12.1 x 1.00 x 12.8 mm

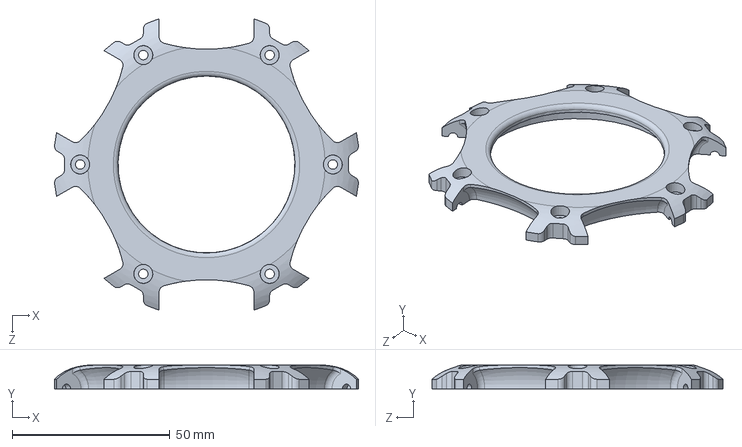
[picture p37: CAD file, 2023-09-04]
Hardware Design/DDOW Part 2.SLDPRT
96.3 x 7.50 x 92.2 mm

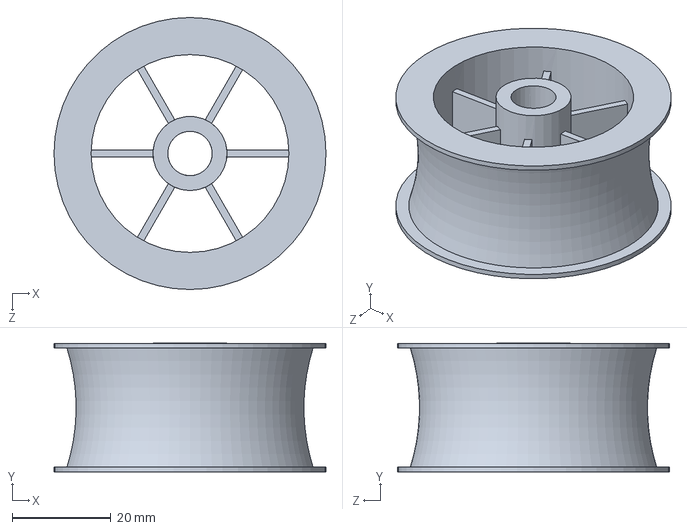
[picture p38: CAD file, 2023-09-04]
Hardware Design/wheel/wheel.SLDPRT
55.0 x 26.0 x 55.0 mm

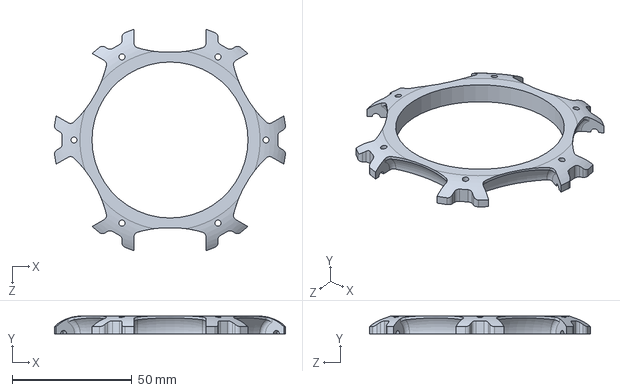
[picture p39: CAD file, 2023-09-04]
Hardware Design/DDOW Part 5.SLDPRT
96.3 x 7.50 x 92.2 mm

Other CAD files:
Hardware Design/h_bridg-motor-drive-l298n-1.snapshot.1/Assem final (H_Bridg)/Dual pin header.SLDPRT
Hardware Design/wheel/Support plate .SLDPRT
Hardware Design/h_bridg-motor-drive-l298n-1.snapshot.1/Assem final (H_Bridg)/Diode.SLDPRT
Hardware Design/Pololu-25D-12V-21kgcm-DCmotor.SLDPRT
Hardware Design/Base tire.SLDPRT
Hardware Design/Base.SLDPRT
Hardware Design/Car Wheel.SLDPRT
Hardware Design/Castor wheel.IGS
Hardware Design/Castor wheel.STEP
Hardware Design/Cross shaft D.SLDPRT
Hardware Design/DDM Bace.SLDPRT
Hardware Design/DDM Cap.SLDPRT
Hardware Design/DDM M3-15mmscrew.SLDPRT
Hardware Design/DDM Rotor.SLDPRT
Hardware Design/DDOW M3-15mmscrew.SLDPRT
Hardware Design/DDOW Part 3.SLDPRT
Hardware Design/DDOW Roller Shaft.SLDPRT
Hardware Design/DDOW Roller.SLDPRT
Hardware Design/DDOW Suport Shaft.SLDPRT
Hardware Design/DDm Stator laminet.SLDPRT
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

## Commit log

2023-09-03 Circuit Diagram
2023-09-04 All Project Data
    [Assem1 (H_Bridg motor drive L298N).SLDASM, Assem2.SLDASM, BCP.SLDPRT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]
